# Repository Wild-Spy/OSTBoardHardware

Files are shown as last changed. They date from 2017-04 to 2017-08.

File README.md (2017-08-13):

# Open Source Timer Board Hardware
#### Rev 1.1

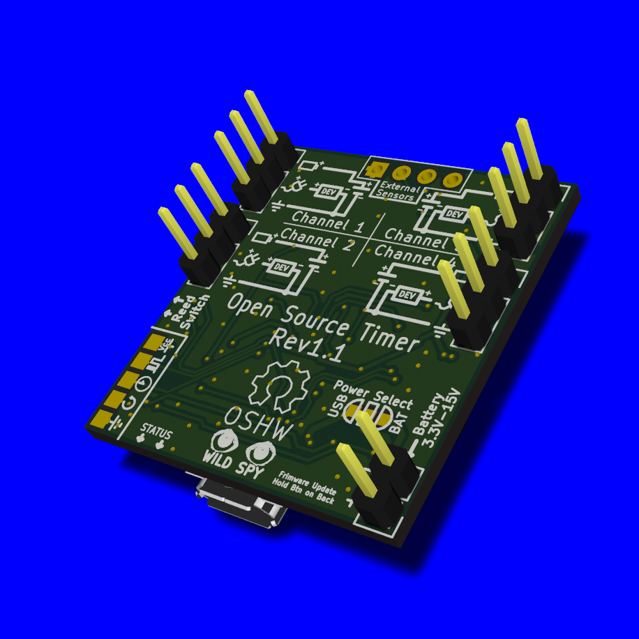
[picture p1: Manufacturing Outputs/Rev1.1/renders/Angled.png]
Rev1.1 PCB


This repository contains the design for the Open Source Timer board.

These files were created in [KiCad](http://kicad-pcb.org/) 

Rev 1.1 contains
 - Schematic
 - PCB
 - Gerbers
 - BOM
 - PnP File
 - Renders
 - Libs
 - 3D Models

### Latest Version
Latest version is [Rev1.1](https://github.com/Wild-Spy/OSTBoardHardware/tree/rev1.1).  See that tag for more info.

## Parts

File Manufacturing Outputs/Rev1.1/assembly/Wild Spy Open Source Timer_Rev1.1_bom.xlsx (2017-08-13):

Component | Description | Part | References | Value | Footprint | Quantity Per PCB | Build Quantity | Datasheet | fit_field | Supplier 1 | Supplier 1 Part Number | Supplier 1 Cost | Supplier 1 Currency | Capacitance | Rated Voltage | Temperature Coefficient | Tolerance | Vdss | Rds(on) | Accuracy | Manufacturer Part Number 1 | Manufacturer 1 | Type | Switching Current | Manufacturer Part Number | Cost Per Board
1 | Connector 01x02 | CONN_01X02 | Battery1 | CONN_01X02 | Pin_Header_Straight_1x02 | 1 | 100 |  | dnf |  |  |  | AUD |  |  |  |  |  |  |  |  |  |  |  |  | 0 | AUD
2 | Unpolarized capacitor | C_Small | C1 C2 C3 C4 | 0.1uF | C_0603_HandSoldering | 4 | 400 |  |  | DigiKey | 1276-1011-1-ND | 0.0062 | AUD |  |  |  |  |  |  |  |  |  |  |  |  | 0.0248 | AUD
3 | Unpolarized capacitor | C_Small | C6 | 1uF | C_0603_HandSoldering | 1 | 100 |  |  | DigiKey | 1276-1182-1-ND | 0.018 | AUD |  |  |  |  |  |  |  |  |  |  |  |  | 0.018 | AUD
4 | 1uF 0805 X5R 50V 10% | CL10A105KB8NNNC | C5 | CL10A105KB8NNNC | C_0805 | 1 | 100 | http://www.samsungsem.com/kr/support/product-search/mlcc/__icsFiles/afieldfile/2016/08/18/S_CL10A105KB8NNNC.pdf |  | DigiKey | 1276-1860-1-ND | 0.0653 | AUD | 1uF | 50V | X5R | 10% |  |  |  |  |  |  |  |  | 0.0653 | AUD
5 | 2.2uF 0603 X7R 6.3V 10% | CL10B225KQ8NFNC | C8 | CL10B225KQ8NFNC | C_0603 | 1 | 100 | http://www.samsungsem.com/kr/front/downloadcms.do?fileName=C_CL10B225KQ8NFNC.pdf |  | DigiKey | 1276-2017-1-ND | 0.0356 | AUD | 2.2uF | 6.3V | X7R | 10% |  |  |  |  |  |  |  |  | 0.0356 | AUD
6 | Connector 01x03 | CONN_01X03 | CH1 CH2 CH3 CH4 | CONN_01X03 | Pin_Header_Straight_1x03 | 4 | 400 |  | dnf |  |  |  | AUD |  |  |  |  |  |  |  |  |  |  |  |  | 0 | AUD
7 |  | LED-RESCUE-Wild_Spy_Open_Source_Timer | D1 | LED | LED_0603 | 1 | 100 | http://www.osram-os.com/Graphics/XPic9/00128792_0.pdf |  | DigiKey | 475-2512-1-ND | 0.1308 | AUD |  |  |  |  |  |  |  |  |  |  |  |  | 0.1308 | AUD
8 |  | JUMPER3 | JP1 | JUMPER3 | SOLDER-JUMPER_2-WAY | 1 | 100 |  | dnf |  |  |  | AUD |  |  |  |  |  |  |  |  |  |  |  |  | 0 | AUD
9 | Connector 01x04 | CONN_01X04 | PBus1 | CONN_01X04 | Pin_Header_Straight_1x04_Pitch2.54mm | 1 | 100 |  | dnf |  |  |  | AUD |  |  |  |  |  |  |  |  |  |  |  |  | 0 | AUD
10 | Transistor P-MOSFET (general) | Q_PMOS_GSD | Q1 Q2 Q3 Q4 Q5 Q6 | AO3415 | SOT-23-HandSoldering | 6 | 600 | http://aosmd.com/res/data_sheets/AO3415.pdf |  | DigiKey | 785-1010-2-ND | 0.11771 | AUD |  |  |  |  | -20V | 53mOhm |  |  |  |  |  |  | 0.70626 | AUD
11 | Transistor N-MOSFET (general) | Q_NMOS_GSD | Q7 | BSH103 | SOT-23-HandSoldering | 1 | 100 | https://assets.nexperia.com/documents/data-sheet/BSH103.pdf |  | Digikey | 1727-4319-1-ND | 0.419 | AUD |  |  |  |  |  |  |  |  |  |  |  |  | 0.419 | AUD
12 | Resistor | R | R4 R5 R6 R7 R12 | 100k | R_0603_HandSoldering | 5 | 500 |  |  | DigiKey | 311-100KGRCT-ND | 0.006 | AUD |  |  |  |  |  |  |  |  |  |  |  |  | 0.03 | AUD
13 | Resistor | R | R1 R2 R8 | 10k | R_0603_HandSoldering | 3 | 300 |  |  | DigiKey | 311-10KGRCT-ND | 0.006 | AUD |  |  |  |  |  |  | 5% |  |  |  |  |  | 0.018 | AUD
14 | Resistor | R | R3 | 150k | R_0603_HandSoldering | 1 | 100 |  |  | DigiKey | 311-150KGRCT-ND | 0.006 | AUD |  |  |  |  |  |  | 5% |  |  |  |  |  | 0.006 | AUD
15 | Resistor | R | R9 R11 | 1k | R_0603_HandSoldering | 2 | 200 |  |  | DigiKey | 311-1.0KGRCT-ND | 0.006 | AUD |  |  |  |  |  |  | 5% |  |  |  |  |  | 0.012 | AUD
16 | Resistor | R | R10 | 2k | R_0603_HandSoldering | 1 | 100 |  |  | DigiKey | 311-2.0KGRCT-ND | 0.006 | AUD |  |  |  |  |  |  | 5% |  |  |  |  |  | 0.006 | AUD
17 | NO Reed Switch | ORD213 | SW2 | ORD213 | ORD213S-1 | 1 | 100 | https://standexelectronics.com/wp-content/uploads/OKI_Reed_Switch_ORD213.pdf |  | Digi Key | 374-1087-ND | 1.7268 | AUD |  | 24 V |  |  |  |  |  | ORD213S-1-1015 | Standex-Meder Electronics | SPST-NO | 100mA |  | 1.7268 | AUD
18 | Button | SW_PUSH | SW1 | SW_PUSH | KMT071NGJLHS_3x2.6mm_switch | 1 | 100 |  |  | DigiKey | CKN10291CT-ND | 0.39 | AUD |  |  |  |  |  |  |  |  |  |  |  |  | 0.39 | AUD
19 | Connector 01x05 | CONN_01X05 | SWD1 | CONN_01X05 | SWD_PROG_HEADER_L | 1 | 100 |  | dnf |  |  |  | AUD |  |  |  |  |  |  |  |  |  |  |  |  | 0 | AUD
20 |  | ATSAMD21E16B | U5 | ATSAMD21E16B | QFN-32-1EP_5x5mm_Pitch0.5mm | 1 | 100 | http://www.atmel.com/Images/Atmel-42181-SAM-D21_Datasheet.pdf |  | DigiKey | 1611-ATSAMD21E18A-MUTCT-ND | 3.014 | AUD |  |  |  |  |  |  |  |  |  |  |  | ATSAMD21E18A-MUT | 3.014 | AUD
21 | I2C RTC with Integrated Crystal | DS3232SN | U1 | DS3232SN | SOIC-20_7.5x12.8mm_Pitch1.27mm | 1 | 100 | http://datasheets.maximintegrated.com/en/ds/DS3232.pdf |  | DigiKey | DS3232SN#T&RCT-ND | 8.3505 | AUD |  |  |  |  |  |  |  |  |  |  |  |  | 8.3505 | AUD
22 |  | TPS70925DBVR | U2 | TPS70933DBVR | SOT-23-5_HandSoldering | 1 | 100 | http://www.ti.com/lit/ds/symlink/tps709.pdf |  | DigiKey | 296-35483-1-ND | 1.19 | AUD |  |  |  |  |  |  |  |  |  |  |  |  | 1.19 | AUD
23 | Dual N Channel MOSFETs | UM6K33N | U3 U4 | UM6K33N | SC88(SOT363) | 2 | 200 | http://rohmfs.rohm.com/en/products/databook/datasheet/discrete/transistor/mosfet/um6k33n.pdf |  | DigiKey | UM6K33NTNTR-ND | 0.08638 | AUD |  |  |  |  |  |  |  |  |  |  |  |  | 0.17276 | AUD
24 | micro connector | micro_USB | USB1 | micro_USB | micro_USB | 1 | 100 | http://portal.fciconnect.com/Comergent//fci/drawing/10118192.pdf |  | DigiKey | 609-4613-1-ND | 0.4163 | AUD |  |  |  |  |  |  |  |  |  |  |  |  | 0.4163 | AUD
 |  |  |  |  |  |  |  |  |  |  |  |  |  |  |  |  |  |  |  |  |  |  |  |  |  | 16.73212 | AUD
Component Groups: | 24
Component Count: | 43
Fitted Components: | 43
Number of PCBs: | 100
Total components: | 4300
Component Cost per PCB:
Total Component Cost: | 16.73212 | AUD
Schematic Version: | 1673.212 | AUD
Schematic Date:
BoM Date: | Sun 13 Aug 2017 18:39:40 AEST
Schematic Source: | /home/mcochrane/build/OSTBoardHardware/Wild Spy Open Source Timer.sch
KiCad Version: | Eeschema 4.0.2+dfsg1-stable

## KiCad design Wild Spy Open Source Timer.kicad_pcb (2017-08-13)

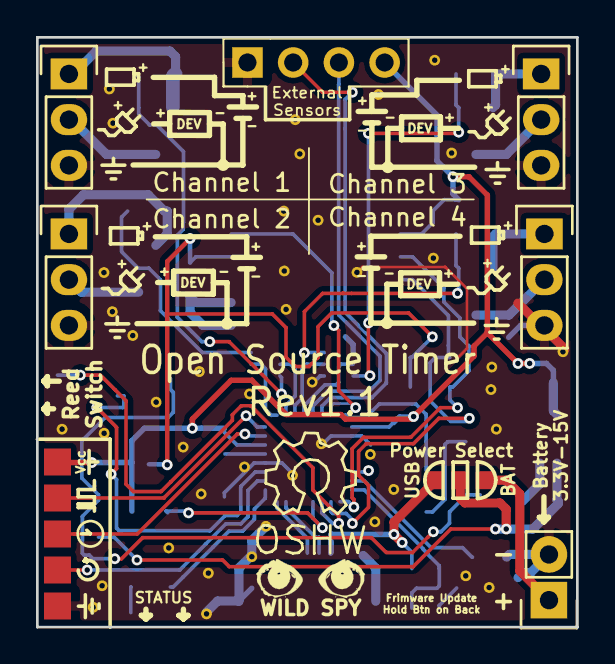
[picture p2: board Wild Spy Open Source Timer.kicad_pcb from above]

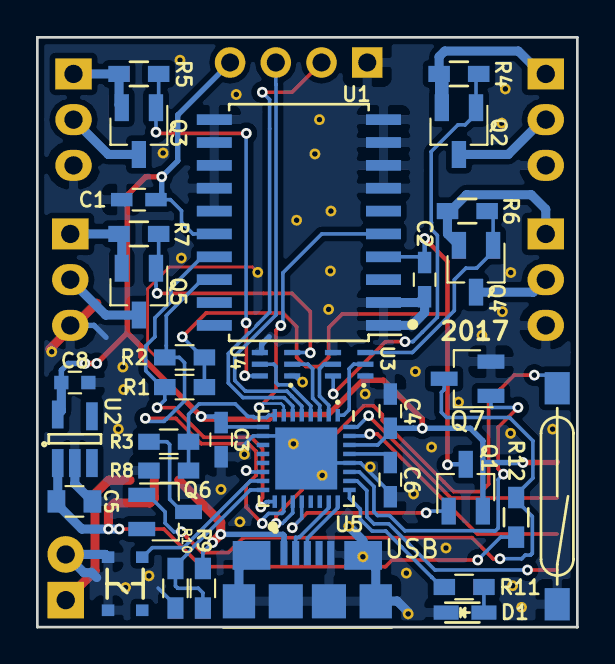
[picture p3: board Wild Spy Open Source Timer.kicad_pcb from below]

Board: 2 copper layers, 30.0 x 32.8 mm, 43 parts (35 on the bottom side), 43 nets.

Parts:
Battery1: CONN_01X02; Pin_Header_Straight_1x02
C1, C2, C3, C4: 0.1uF; C_0603_HandSoldering
C5: CL10A105KB8NNNC; C_0805
C6: 1uF; C_0603_HandSoldering
C8: CL10B225KQ8NFNC; C_0603
CH1, CH2, CH3, CH4: CONN_01X03; Pin_Header_Straight_1x03
D1: LED; LED_0603
JP1: JUMPER3; SOLDER-JUMPER_2-WAY
PBus1: CONN_01X04; Pin_Header_Straight_1x04_Pitch2.54mm
Q1, Q2, Q3, Q4, Q5, Q6: AO3415; SOT-23-HandSoldering
Q7: BSH103; SOT-23-HandSoldering
R1, R2, R8: 10k; R_0603_HandSoldering
R3: 150k; R_0603_HandSoldering
R4, R5, R6, R7, R12: 100k; R_0603_HandSoldering
R9, R11: 1k; R_0603_HandSoldering
R10: 2k; R_0603_HandSoldering
SW1: SW_PUSH; KMT071NGJLHS_3x2.6mm_switch
SW2: ORD213; ORD213S-1
SWD1: CONN_01X05; SWD_PROG_HEADER_L
U1: DS3232SN; SOIC-20_7.5x12.8mm_Pitch1.27mm
U2: TPS70933DBVR; SOT-23-5_HandSoldering
U3, U4: UM6K33N; SC88(SOT363)
U5: ATSAMD21E16B; QFN-32-1EP_5x5mm_Pitch0.5mm
USB1: micro_USB

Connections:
+5V: JP1.1, R9.1, USB1.1
/BAT+: Battery1.1, JP1.3
/BL_FW_UPDATE: SW1.1, U5.15
/BatMeasureEn: Q7.1, U5.27
/CH1_EN: U3.2, U5.1
/CH2_EN: U3.5, U5.2
/CH3_EN: U4.2, U5.3
/CH4_EN: U4.5, U5.4
/D+: U5.24, USB1.3
/D-: U5.23, USB1.2
/LED: R11.1, U5.25
/NRESET: SWD1.4, U5.26
/PBus1_MRX: PBus1.2, U5.6
/PBus1_MTX: PBus1.3, U5.5
/REEDSW: SW2.1, U5.19
/RTC_~INT: U1.5, U5.7
/SCL: R2.2, U1.18, U5.18
/SDA: R1.2, U1.17, U5.17
/SWDCLK: SWD1.3, U5.31
/SWDIO: SWD1.2, U5.32
/USBSENSE3.3: R9.2, R10.1, U5.16
/VBat/15: R3.2, R8.1, U5.8
/~RTC_PEN: Q1.1, U5.20
GND: Battery1.2, C1.1, C2.1, C3.2, C4.1, C5.2, C6.1, C8.2, CH1.3, CH2.3, CH3.3, CH4.3, D1.1, PBus1.1, Q7.2, R8.2, R10.2, SW1.2, SW2.2, SWD1.5, U1.1, U1.2, U1.7, U1.8, U1.9, U1.10, U1.11, U1.12, U1.13, U1.14, U1.15, U2.2, U3.1, U3.4, U4.1, U4.4, U5.10, U5.28, U5.33, USB1.5, USB1.6
unnamed: C2.2, Q1.3, R1.1, R2.1, U1.4
unnamed: C6.2, U5.29
unnamed: CH1.1, Q2.2, R4.1
unnamed: CH1.2, Q2.3
unnamed: CH2.1, Q4.2, R6.1
unnamed: CH2.2, Q4.3
unnamed: CH3.1, Q3.2, R5.1
unnamed: CH3.2, Q3.3
unnamed: CH4.1, Q5.2, R7.1
unnamed: CH4.2, Q5.3
unnamed: D1.2, R11.2
unnamed: Q2.1, R4.2, U3.6
unnamed: Q3.1, R5.2, U4.6
unnamed: Q4.1, R6.2, U3.3
unnamed: Q5.1, R7.2, U4.3
unnamed: Q6.1, Q7.3, R12.2
unnamed: Q6.3, R3.1
VAA: C5.1, JP1.2, Q6.2, R12.1, U2.1
VCC: C1.2, C3.1, C4.2, C8.1, PBus1.4, Q1.2, SWD1.1, U1.16, U2.5, U5.9, U5.30

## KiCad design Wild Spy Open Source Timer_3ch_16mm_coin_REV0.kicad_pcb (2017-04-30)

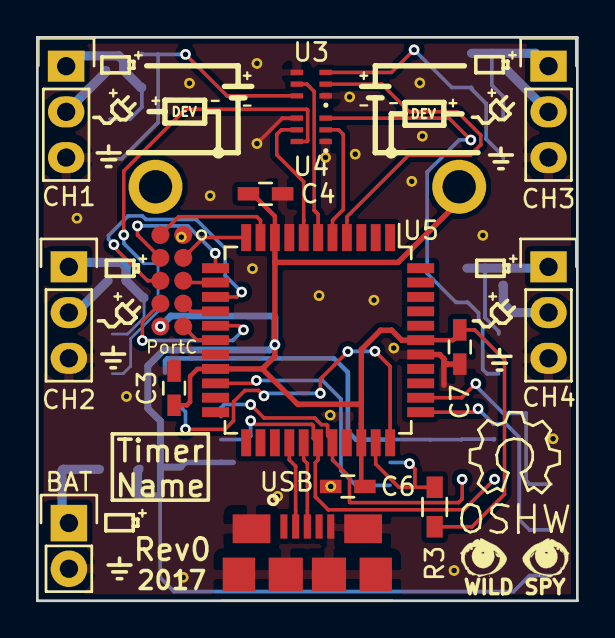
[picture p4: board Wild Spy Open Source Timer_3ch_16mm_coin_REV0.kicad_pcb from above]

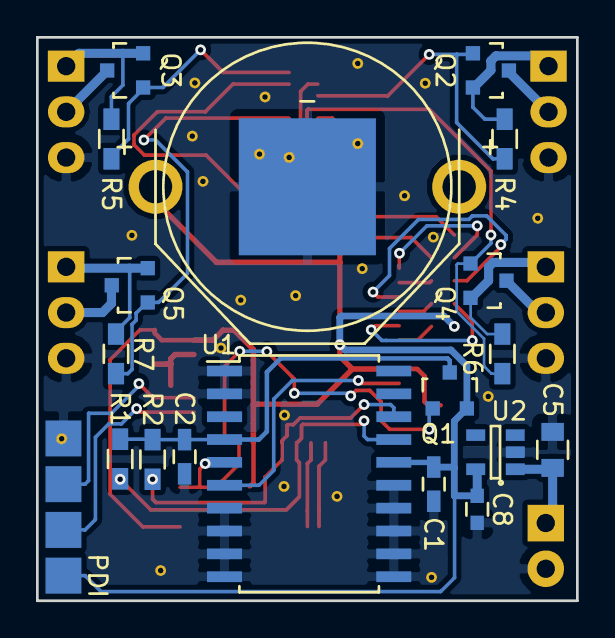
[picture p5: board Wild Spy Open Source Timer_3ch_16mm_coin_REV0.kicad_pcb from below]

Board: 2 copper layers, 30.0 x 31.3 mm, 34 parts (19 on the bottom side), 37 nets.

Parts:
Battery1: CONN_01X02; Pin_Header_Straight_1x02
C1, C2, C3, C4, C6, C7: 0.1uF; C_0603_HandSoldering
C5: CL10A105KB8NNNC; C_0805
C8: CL10B225KQ8NFNC; C_0603
CH1, CH2, CH3, CH4: CONN_01X03; Pin_Header_Straight_1x03
Coin1: 16mm_Coin_Cell; CoinCell_Holder_1632
PDI1: CONN_01X04; PDI_PROG_HEADER
PortC: CONN_01X10; 5x2connnector_small
Q1, Q2, Q3, Q4, Q5: AO3415; SOT-23
R1, R2, R3, R4, R5, R6, R7: 10k; R_0603_HandSoldering
U1: DS3232SN; SOIC-20_7.5x12.8mm_Pitch1.27mm
U2: TPS70925DBVR; SOT-23-5
U3, U4: UM6K33N; SC88(SOT363)
U5: ATXMEGA32C4-A; TQFP-44_10x10mm_Pitch0.8mm
USB1: micro_USB

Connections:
/CH1_EN: U3.2, U5.4
/CH2_EN: U4.2, U5.5
/CH3_EN: U3.5, U5.6
/CH4_EN: U4.5, U5.7
/D+: U5.27, USB1.3
/D-: U5.26, USB1.2
/PC0: PortC.2, U5.10
/PC1: PortC.3, U5.11
/PC2: PortC.4, U5.12
/PC3: PortC.5, U5.13
/PC4: PortC.6, U5.14
/PC5: PortC.7, U5.15
/PC6: PortC.8, U5.16
/PC7: PortC.9, U5.17
/PDI_CLK: PDI1.3, U5.35
/PDI_DATA: PDI1.2, U5.34
/RTC_~INT: R3.2, U1.5, U5.32
/SCL: R2.2, U1.18, U5.29
/SDA: R1.2, U1.17, U5.28
/~RST: U1.6, U5.20
/~RTC_PEN: Q1.1, U5.33
GND: Battery1.2, C1.1, C2.1, C3.1, C4.1, C5.2, C6.1, C7.1, C8.2, CH1.3, CH2.3, CH3.3, CH4.3, Coin1.2, PDI1.4, PortC.1, U1.1, U1.2, U1.7, U1.8, U1.9, U1.10, U1.11, U1.12, U1.13, U1.14, U1.15, U2.2, U3.1, U3.4, U4.1, U4.4, U5.8, U5.18, U5.30, U5.38, USB1.5, USB1.6
unnamed: C2.2, Q1.3, R1.1, R2.1, U1.4
unnamed: CH1.1, Q2.2, R4.1
unnamed: CH1.2, Q2.3
unnamed: CH2.1, Q4.2, R6.1
unnamed: CH2.2, Q4.3
unnamed: CH3.1, Q3.2, R5.1
unnamed: CH3.2, Q3.3
unnamed: CH4.1, Q5.2, R7.1
unnamed: CH4.2, Q5.3
unnamed: Q2.1, R4.2, U3.6
unnamed: Q3.1, R5.2, U3.3
unnamed: Q4.1, R6.2, U4.6
unnamed: Q5.1, R7.2, U4.3
VAA: Battery1.1, C5.1, U2.1
VCC: C1.2, C3.2, C4.2, C6.2, C7.2, C8.1, Coin1.1, PDI1.1, PortC.10, Q1.2, R3.1, U1.16, U2.5, U5.9, U5.19, U5.31, U5.39

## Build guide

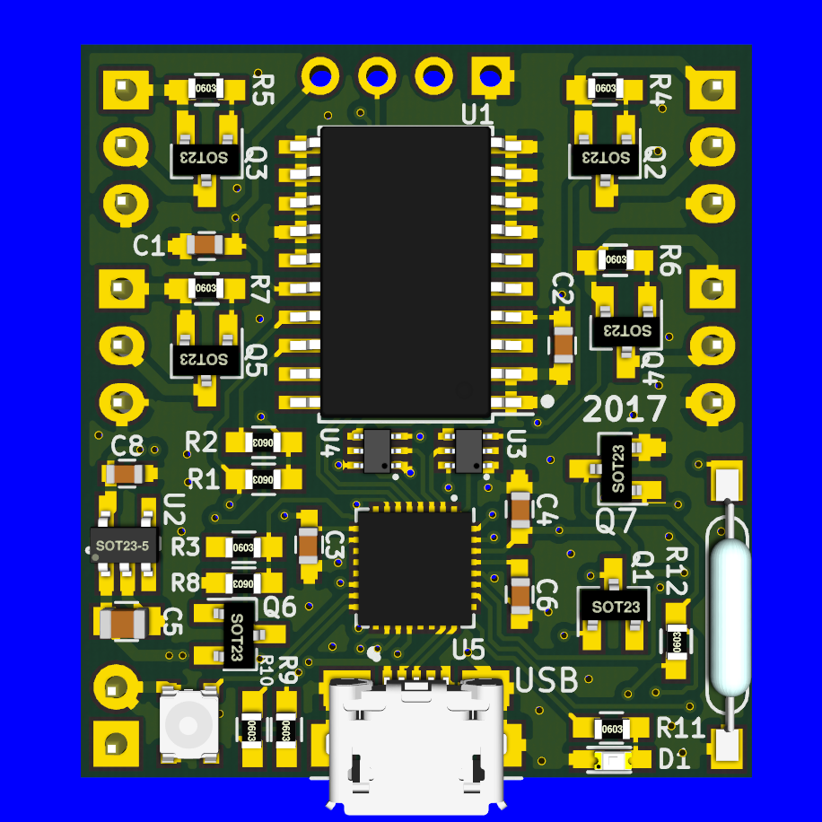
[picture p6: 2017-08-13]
Manufacturing Outputs/Rev1.1/renders/Back.png

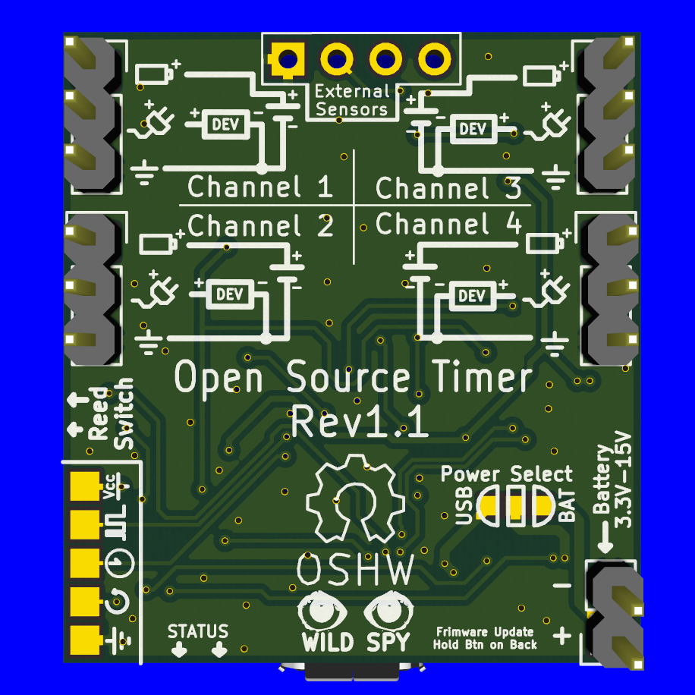
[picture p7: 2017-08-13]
Manufacturing Outputs/Rev1.1/renders/Front.png

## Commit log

2017-04-30 Initial commit with Rev0 design.
    [Wild Spy Open Source Timer.kicad_pcb, Wild Spy Open Source Timer.sch, Wild Spy Open Source Timer_2ch_no_coin_V1.kicad_pcb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]
2017-04-30 Restructure, clean up.
    [Wild Spy Open Source Timer.kicad_pcb, Wild Spy Open Source Timer_2ch_no_coin_V1.kicad_pcb, Wild Spy Open Source Timer_3ch_16mm_coin_REV1.kicad_pcb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]
2017-05-02 Swapped to the d21 in the schematic
    [Wild Spy Open Source Timer.sch]
2017-05-08 - Updates to Rev1 Schematic - Organising/Tidying - Add peripheral bus port - Battery voltage measurement - Battery/USB selection jumper - Started skeleton of Rev1 PCB - Added libs folder with some fo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
    [Wild Spy Open Source Timer.kicad_pcb, Wild Spy Open Source Timer.sch]
2017-05-09 PCB components placed
    [Wild Spy Open Source Timer.kicad_pcb, Wild Spy Open Source Timer.sch]
2017-05-09 Routing for the Timer PCB- almost done
    [Wild Spy Open Source Timer.kicad_pcb]
2017-05-11 Cleaned up routing on PCB a bit. Made some changes to schematic, added a few things.
    [Wild Spy Open Source Timer.kicad_pcb, Wild Spy Open Source Timer.sch]
2017-05-11 Pretty much finished REV1 PCB. Just need to have a quick look over it and export gerbers etc.
    [Wild Spy Open Source Timer.kicad_pcb, Wild Spy Open Source Timer.sch]
2017-05-12 Finished the PCB layout
    [Wild Spy Open Source Timer.kicad_pcb, Wild Spy Open Source Timer.sch]
2017-05-12 Generated Gerbers for Rev1 Generated BOM for Rev1 Generated renders for Rev1 Some updating of paths and libs
    [Wild Spy Open Source Timer-B.Cu.gbl, Wild Spy Open Source Timer-B.Mask.gbs, Wild Spy Open Source Timer-B.Paste.gbp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]
2017-05-12 Fixed bug in library - wrong 3d model for USB Fixed Front layer silkscreen - had no battery reference of voltage range Regenerated Gerbers Regenerated renders
    [Wild Spy Open Source Timer-B.Cu.gbl, Wild Spy Open Source Timer-B.Mask.gbs, Wild Spy Open Source Timer-B.Paste.gbp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]
2017-05-22 The schematic for the wav trigger board. Needs checking. No rats nesting done yet
    [WavTriggerBoard.kicad_pcb, WavTriggerBoard.sch, _saved_Wild Spy Open Source Timer.sch]
2017-05-22 Updated with comments and footprints for the headers
    [WavTriggerBoard.sch]
2017-07-22 Removed Harry's commit of WavTriggerBoard. Should not be in this repo. Updated chip in schematic.
    [WavTriggerBoard.kicad_pcb, WavTriggerBoard.sch, Wild Spy Open Source Timer.kicad_pcb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]
2017-08-08 Fixed battery volrage measurement issue in hardware.
    [Wild Spy Open Source Timer.kicad_pcb, Wild Spy Open Source Timer.sch, _saved_Wild Spy Open Source Timer.sch]
2017-08-13 Manufacturing outputs for Rev1.1
    [Wild Spy Open Source Timer-B.Cu.gbl, Wild Spy Open Source Timer-B.Mask.gbs, Wild Spy Open Source Timer-B.Paste.gbp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]
2017-08-13 Clean up
    [Wild Spy Open Source Timer.kicad_pcb, Wild Spy Open Source Timer_2ch_no_coin_V1.kicad_pcb, Wild Spy Open Source Timer_3ch_16mm_coin_REV1.kicad_pcb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]
